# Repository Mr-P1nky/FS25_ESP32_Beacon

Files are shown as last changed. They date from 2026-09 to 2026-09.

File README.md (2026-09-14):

# FS25 ESP32 Beacon

An ESP32-S3 firmware that emulates the Giants Software USB Beacon light for Farming Simulator 25. Plug it in and your NeoPixel ring mirrors the in-game beacon state automatically — no mods or scripts required.

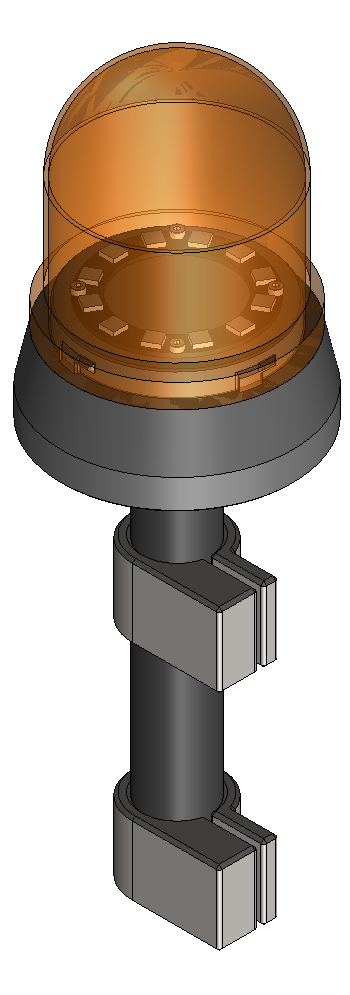
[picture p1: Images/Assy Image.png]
Assembled beacon


## How it works

FS25 has native support for a physical USB beacon accessory (VID `0x340D` / PID `0x1710`). When a vehicle beacon is toggled, the game sends HID output reports to the device. This firmware spoofs that device on an ESP32-S3 and drives a WS2812B NeoPixel ring accordingly.

The game sends a keepalive report every ~3 seconds while the beacon is active, and auto-offs the device after ~10 seconds without one.

## Hardware

> **Affiliate disclosure:** as an Amazon Associate I earn from qualifying purchases.

| Title | Description | Qty | Affiliate Link |
|---|---|-----|---|
| Waveshare ESP32-S3-Zero | ESP32-S3FH4R2 MCU — 4MB flash, 2MB PSRAM, WiFi + BLE 5 | 1 | https://amzn.to/4wRNUeB Waveshare 2pc <br> https://amzn.to/4wIOBa7 Clone 1pc <br> https://amzn.to/45HKDnj Clone 3pc |
| NeoPixel ring | 12x WS2812B addressable LED ring | 1 | https://amzn.to/4A7DNFr |
| M2x6 SHCS | Socket head cap screw (for NeoPixel ring to base) | 4 | TBD |
| M3x12 SHCS | Socket head cap screw (for tube clamps) | 2 | TBD |
| M2x5 countersunk screw | Countersunk machine screw (for ESP cover to base) | 2 | TBD |
| 3M Command small strip | Mounting strip | 2 | https://amzn.to/46WvWgx |
| 3D printed enclosure | Custom design, see [`CAD/`](CAD/) | 1 | — |

Any ESP32-S3 board with TinyUSB support should work. WS2812B ring size is configurable via `LED_COUNT`.

## Assembly

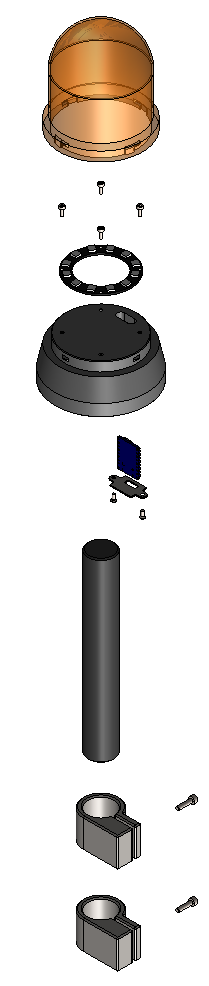
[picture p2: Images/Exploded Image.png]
Exploded view


1. Solder three wires to the ESP32-S3-Zero: data to **GPIO4**, plus **5V** and **GND**.
2. Feed the wires through the base, slot the ESP32 into the base, and secure it with the ESP cover (2x M2x5 countersunk).
3. Trim the wires to length and solder them to the NeoPixel ring.
4. Secure the NeoPixel ring to the base with 4x M2x6 SHCS.
5. Fit the lens and rotate clockwise to secure.
6. Press-fit the tube into the base.
7. Secure the tube clamps to the tube with 2x M3x12 SHCS.
8. Fit the 3M Command strips to the tube clamps.
9. Clean the mounting area (e.g. the back of a monitor) with IPA.
10. Stick the beacon in place.

## Beacon modes

| Game state | Mode byte | Animation |
|---|---|---|
| Beacon off | `0x00` | All off |
| Rotating beacon | `0x01` | Amber chase sweep with fading tail |
| Strobe beacon | `0x07` | Amber flash |

## Arduino IDE setup

1. Install **Arduino ESP32 core >= 3.x** via Boards Manager
2. Install **Adafruit NeoPixel** via Library Manager
3. Select board: `ESP32S3 Dev Module`
4. Set **USB Mode** to `USB-OTG (TinyUSB)`

The Arduino IDE requires a sketch's parent folder to have the exact same name as its `.ino` file. Copy or symlink `Sketch\FS25_ESP32_Beacon.ino` into a folder named `FS25_ESP32_Beacon` before opening it in the IDE.

To flash: hold the BOOT button while plugging in USB, then upload normally.

## game.xml

Ensure your FS25 `game.xml` (in `Documents\My Games\FarmingSimulator2025\`) has:

```xml
<usbBeaconLight enable="true"/>
```

## Notes

- The game scans for the device at startup and re-acquires it automatically if the device re-enumerates
- The HID report descriptor must advertise `OutputReportByteLength = 65` (64-byte output report) — this is what FS25 checks in its device validation code
- The `_onOutput` callback in the ESP32 Arduino TinyUSB framework is only triggered when `report_id == 0` (no Report ID in descriptor); do not add a Report ID

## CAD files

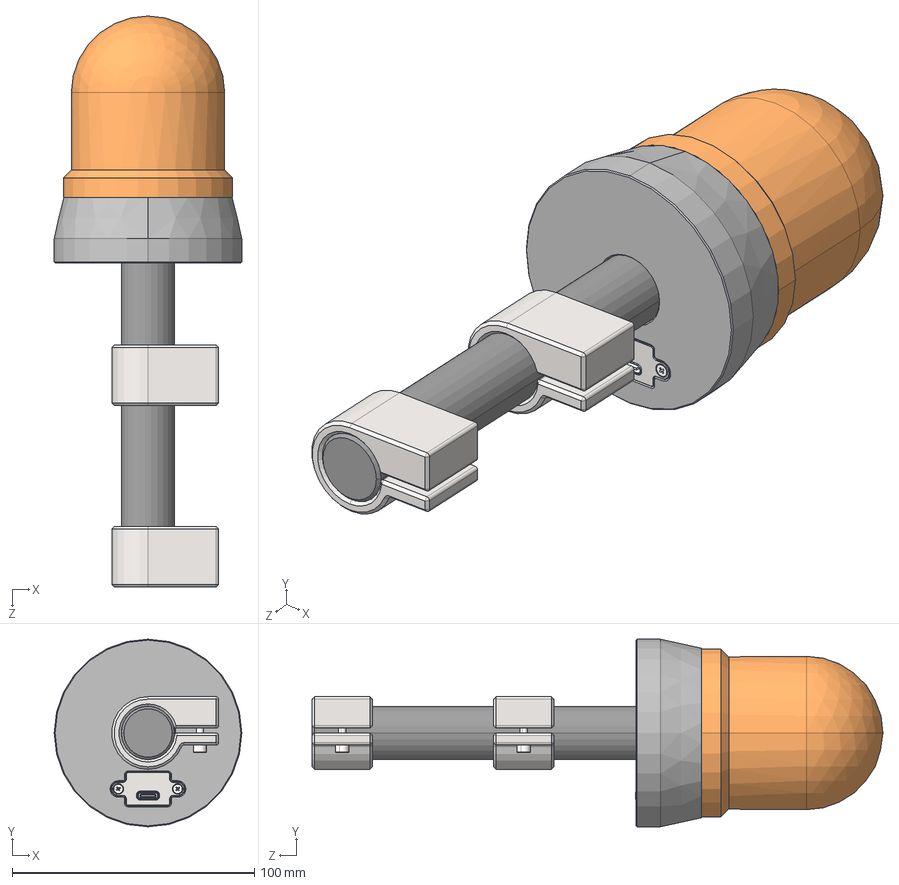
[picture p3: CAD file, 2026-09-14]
CAD/STEP/01 - FSB - 0100 - Main Assy.STEP
77.5 x 77.5 x 235.9 mm
01 - FSB - 1000 - Base
01 - FSB - 1002 - Lens
WCMCU WS2812B-12
ESP32-S3-Zero_v2_No Headers
01 - FSB - 1004 - Tube
socket head cap screw_iso_ISO 4762 M2 x 6 - 6N x 4
01 - FSB - 1001 - ESP Cover
countersunk flat head cross recess screw_iso_ISO 7046-1 - M2 x 5 - Z - 5N x 2
01 - FSB - 1003 - Tube Mount x 2
socket head cap screw_iso_ISO 4762 M3 x 12 - 12N x 2

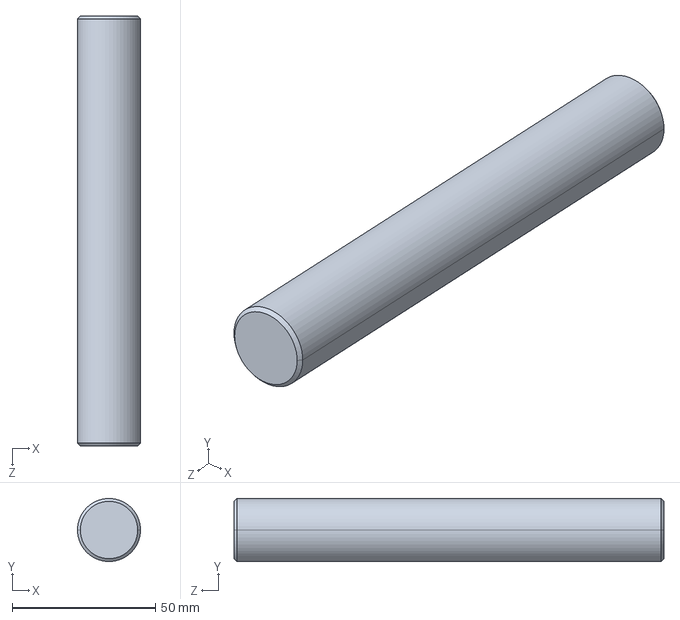
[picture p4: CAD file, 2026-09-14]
CAD/STEP/01 - FSB - 1004 - Tube.STEP
22.0 x 22.0 x 150.0 mm

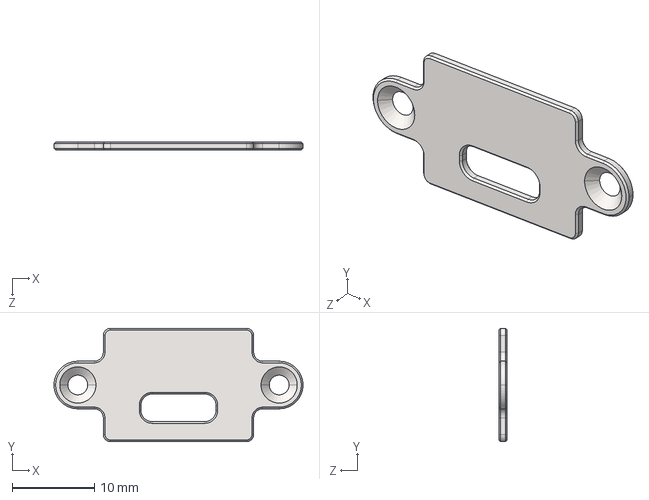
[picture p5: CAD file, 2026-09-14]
CAD/STEP/01 - FSB - 1001 - ESP Cover.STEP
30.3 x 13.8 x 1.00 mm

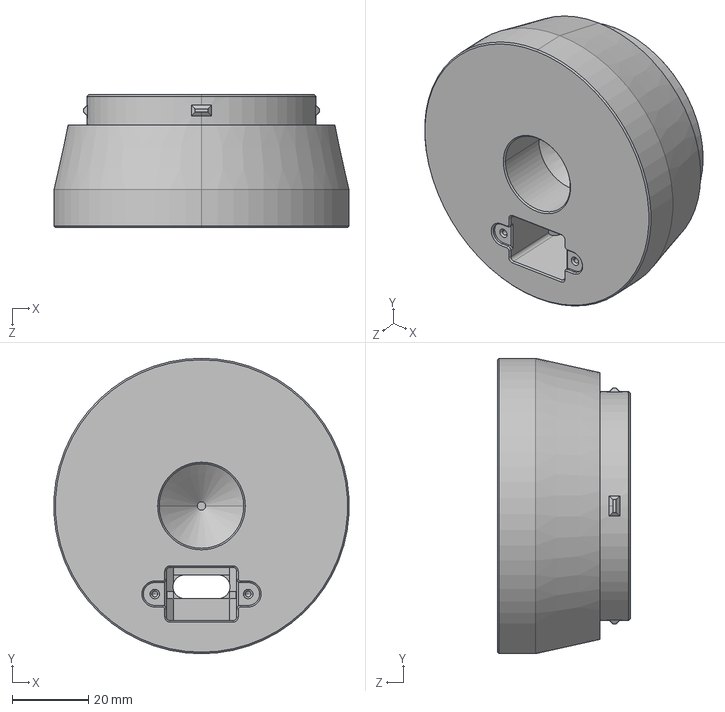
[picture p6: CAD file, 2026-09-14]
CAD/STEP/01 - FSB - 1000 - Base.STEP
77.4 x 77.5 x 35.0 mm

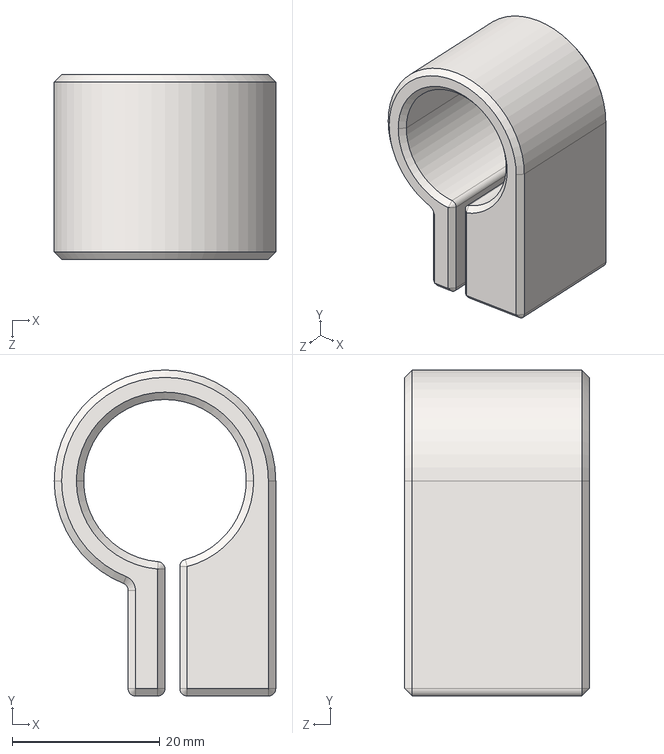
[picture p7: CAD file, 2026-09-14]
CAD/STEP/01 - FSB - 1003 - Tube Mount.STEP
30.0 x 44.1 x 25.0 mm

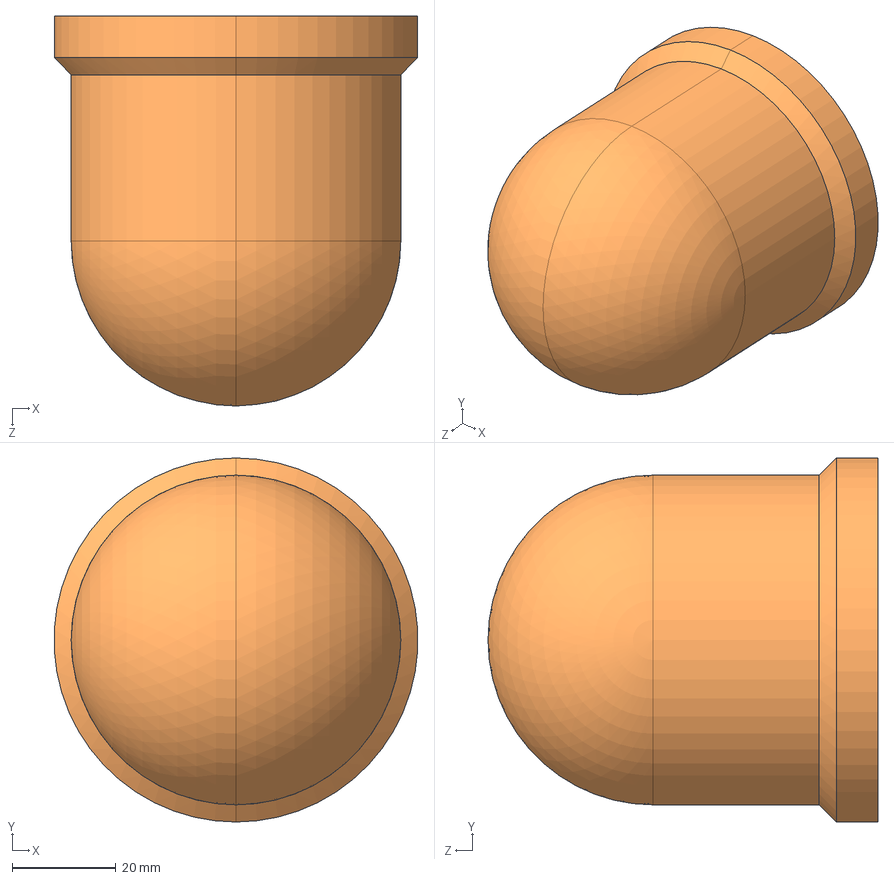
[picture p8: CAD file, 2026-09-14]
CAD/STEP/01 - FSB - 1002 - Lens.STEP
69.9 x 70.0 x 75.0 mm

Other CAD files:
CAD/3MF/01 - FSB - 1000 - Base.3MF
CAD/3MF/01 - FSB - 1001 - ESP Cover.3MF
CAD/3MF/01 - FSB - 1002 - Lens.3MF
CAD/3MF/01 - FSB - 1003 - Tube Mount.3MF
CAD/3MF/01 - FSB - 1004 - Tube.3MF

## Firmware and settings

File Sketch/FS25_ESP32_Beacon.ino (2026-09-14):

/*
 * FS25 ESP32 Beacon
 * Farming Simulator 25 - USB Beacon Light Emulator
 *
 * Emulates the Giants Software USB Beacon (VID: 0x340D, PID: 0x1710)
 * using a Waveshare ESP32-S3-Zero + 12x WS2812B NeoPixel ring.
 *
 * FS25 automatically sends HID output reports to control the beacon state.
 * The NeoPixel ring mirrors the in-game beacon:
 *   Mode 0x00  OFF
 *   Mode 0x01  ROUND (amber chasing sweep)
 *   Mode 0x07  BLINK (amber flash: two quick flashes then a long pause, repeating)
 *
 * Hardware:
 *   Board:     Waveshare ESP32-S3-Zero
 *   NeoPixels: 12x WS2812B ring on GPIO4
 *
 * Arduino IDE settings:
 *   Board:           ESP32S3 Dev Module
 *   USB Mode:        USB-OTG (TinyUSB)
 *   USB CDC On Boot: Enabled or Disabled both work - CDC is a separate
 *                    USB interface and doesn't affect the HID descriptor
 *                    FS25 checks against.
 *
 * To flash: hold BOOT while plugging in USB, then upload normally.
 *
 * Libraries: Adafruit NeoPixel, Arduino ESP32 core >= 3.x
 */

#include "USB.h"
#include "USBHID.h"
#include <Adafruit_NeoPixel.h>
extern USBHID HID;

// ── Hardware ──────────────────────────────────────────────────────────────────
#define LED_PIN     4
#define LED_COUNT   12
#define BRIGHTNESS  255  // 0-255, tuned for visibility through the housing

// ── Beacon colours ────────────────────────────────────────────────────────────
#define BEACON_AMBER  0xFF3700   // amber/orange, tuned through housing (R255 G55 B0)
#define BEACON_OFF    0x000000

// ── NeoPixel ─────────────────────────────────────────────────────────────────
Adafruit_NeoPixel ring(LED_COUNT, LED_PIN, NEO_GRB + NEO_KHZ800);

// ── USB HID descriptor ────────────────────────────────────────────────────────
// Minimal HID descriptor: vendor-defined, 10-byte output report
static const uint8_t giants_hid_descriptor[] = {
  0x06, 0x00, 0xFF,   // Usage Page (Vendor Defined 0xFF00)
  0x09, 0x01,         // Usage (Vendor Usage 1)
  0xA1, 0x01,         // Collection (Application)

  // No Report ID — framework only calls _onOutput when report_id == 0
  0x09, 0x01,         //   Usage (Vendor Usage 1)
  0x15, 0x00,         //   Logical Minimum (0)
  0x26, 0xFF, 0x00,   //   Logical Maximum (255)
  0x75, 0x08,         //   Report Size (8)
  0x95, 0x40,         //   Report Count (64) ← 64 input bytes
  0x81, 0x02,         //   Input (Data, Variable, Absolute)

  0x09, 0x01,         //   Usage (Vendor Usage 1)
  0x15, 0x00,         //   Logical Minimum (0)
  0x26, 0xFF, 0x00,   //   Logical Maximum (255)
  0x75, 0x08,         //   Report Size (8)
  0x95, 0x40,         //   Report Count (64) ← 64 output bytes → OutputReportByteLength=65
  0x91, 0x02,         //   Output (Data, Variable, Absolute)

  0xC0                // End Collection
};

// ── HID device class ─────────────────────────────────────────────────────────
class GiantsBeaconHID : public USBHIDDevice {
public:
  GiantsBeaconHID() {}

  void begin() {
    // Register with TinyUSB stack
    HID.addDevice(this, sizeof(giants_hid_descriptor));
  }

  uint16_t _onGetDescriptor(uint8_t* dst) override {
    memcpy(dst, giants_hid_descriptor, sizeof(giants_hid_descriptor));
    return sizeof(giants_hid_descriptor);
  }

  // Called by TinyUSB when the host sends an output report (i.e. the game)
  void _onOutput(uint8_t report_id, const uint8_t* buffer, uint16_t len) override {
    // No LED calls here — USB callbacks must not block
    // Real payload: [0xFF, mode, ...] — byte[0]=0xFF always, byte[1]=mode
    uint8_t mode = (len >= 2) ? buffer[1] : buffer[0];
    BeaconState newState = beaconState;
    if      (mode == 0x00) newState = STATE_OFF;
    else if (mode == 0x01) newState = STATE_ROUND;
    else if (mode == 0x07) newState = STATE_BLINK;

    if (newState == STATE_BLINK && beaconState != STATE_BLINK) {
      blinkResetRequested = true;
    }
    beaconState = newState;
  }

  volatile bool blinkResetRequested = false;

  enum BeaconState { STATE_OFF, STATE_ROUND, STATE_BLINK };
  volatile BeaconState beaconState = STATE_OFF;
};

USBHID HID;
GiantsBeaconHID beaconHID;


// ── Animation state ───────────────────────────────────────────────────────────
uint8_t  chasePos    = 0;
uint32_t lastStep    = 0;

#define CHASE_INTERVAL_MS   60    // speed of rotating sweep
#define CHASE_TAIL          4     // number of lit pixels in the sweep

// Blink sequence measured from real FS25 footage (60fps frame analysis):
// two quick flashes then a long pause, 883ms total cycle.
const uint32_t blinkSequence[]   = { 67, 67, 67, 682 };
const bool     blinkSequenceOn[] = { true, false, true, false };
#define BLINK_SEQUENCE_LEN  (sizeof(blinkSequence) / sizeof(blinkSequence[0]))

uint8_t  blinkStep     = 0;
uint32_t blinkStepStart = 0;

// ── Helpers ───────────────────────────────────────────────────────────────────

// Dim a colour by a 0-255 factor
uint32_t dimColour(uint32_t colour, uint8_t brightness) {
  uint8_t r = (uint8_t)(colour >> 16);
  uint8_t g = (uint8_t)(colour >>  8);
  uint8_t b = (uint8_t)(colour      );
  return ring.Color(
    (r * brightness) / 255,
    (g * brightness) / 255,
    (b * brightness) / 255
  );
}

void animateRound() {
  uint32_t now = millis();
  if (now - lastStep < CHASE_INTERVAL_MS) return;
  lastStep = now;

  ring.clear();
  for (int i = 0; i < CHASE_TAIL; i++) {
    int pixel = (chasePos - i + LED_COUNT) % LED_COUNT;
    // Fade the tail: brightest at head, dimmer toward tail
    uint8_t fade = 255 - (i * (255 / CHASE_TAIL));
    ring.setPixelColor(pixel, dimColour(BEACON_AMBER, fade));
  }
  ring.show();
  chasePos = (chasePos + 1) % LED_COUNT;
}

void animateBlink() {
  uint32_t now = millis();
  if (beaconHID.blinkResetRequested) {
    beaconHID.blinkResetRequested = false;
    blinkStep = 0;
    blinkStepStart = now;
    for (int i = 0; i < LED_COUNT; i++) ring.setPixelColor(i, BEACON_AMBER);
    ring.show();
    return;
  }
  if (now - blinkStepStart >= blinkSequence[blinkStep]) {
    blinkStep = (blinkStep + 1) % BLINK_SEQUENCE_LEN;
    blinkStepStart = now;

    if (blinkSequenceOn[blinkStep]) {
      for (int i = 0; i < LED_COUNT; i++) ring.setPixelColor(i, BEACON_AMBER);
    } else {
      ring.clear();
    }
    ring.show();
  }
}

void allOff() {
  ring.clear();
  ring.show();
}

// ── Setup ─────────────────────────────────────────────────────────────────────
void setup() {
  // Set USB VID/PID to match Giants beacon hardware
  USB.VID(0x340D);
  USB.PID(0x1710);
  USB.manufacturerName("GIANTS Software");
  USB.productName("Beacon");

  HID.begin();
  beaconHID.begin();
  USB.begin();

  ring.begin();
  ring.setBrightness(BRIGHTNESS);

  // Startup test: sweep amber around the ring to confirm hardware works
  for (int i = 0; i < LED_COUNT; i++) {
    ring.clear();
    ring.setPixelColor(i, BEACON_AMBER);
    ring.show();
    delay(60);
  }
  ring.clear();
  ring.show();
}

// ── Loop ──────────────────────────────────────────────────────────────────────
void loop() {
  switch (beaconHID.beaconState) {
    case GiantsBeaconHID::STATE_ROUND:
      animateRound();
      break;
    case GiantsBeaconHID::STATE_BLINK:
      animateBlink();
      break;
    case GiantsBeaconHID::STATE_OFF:
    default:
      allOff();
      break;
  }
}

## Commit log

2026-05-29 Initial release: FS25 ESP32-S3 USB beacon emulator
2026-09-14 Reorganise repo layout and update hardware BoM
    - Move sketch into Sketch/, add CAD models and assembly image
    - Update hardware to Waveshare ESP32-S3-Zero with affiliate BoM table
    - Document Arduino IDE folder-naming requirement for the sketch
    [01 - FSB - 0100 - Main Assy.STEP, 01 - FSB - 1000 - Base.3MF, 01 - FSB - 1000 - Base.STEP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]
2026-09-14 Add assembly guide, exploded view, and BoM fixings/mounting details
    - Add exploded image and step-by-step physical assembly instructions
    - Clarify fixing purposes in BoM (ring mount, tube clamps, ESP cover)
    - Add 3M Command strips for monitor mounting
